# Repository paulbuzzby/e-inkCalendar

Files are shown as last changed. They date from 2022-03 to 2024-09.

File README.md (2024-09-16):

# e-inkCalendar

This repo contains the code needed to drive a 7.5" e-ink display and act as a calendar. This project uses a battery powered (PiSugar2) Raspberry Pi Zero 2 WH (or install your own headers). Calendar events are retrived from Micrsoft Outlook.com.
The layout is based off how the iOS Outlook client shows calendar information. This felt like the best use for the 480x800 space available in the e-ink display.

This project was inspired by [MagInkCal](https://github.com/speedyg0nz/MagInkCal/blob/main/README.md) and some of his code does appear in this project. That project uses a much bigger e-ink display and they are a lot more expensive than the display I have used here.

I created this project as a way to learn python and github while building something usful. The device is magentically attached to my kitchen fridge. Updates as 6am every morning to show me todays planned events along with as many future events that can fit on the page.
Battery percentage is shown in the top right so you know when to recharge and a timestamp of the last sucessful screen update is shown in the bottom left on the screen.

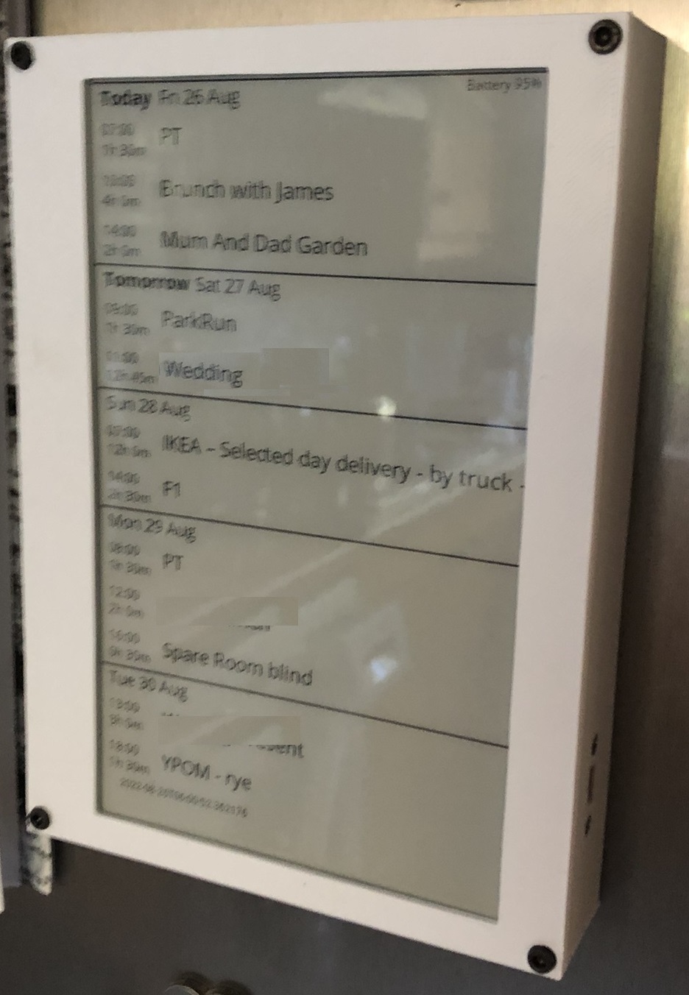
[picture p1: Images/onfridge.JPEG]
On the Fridge


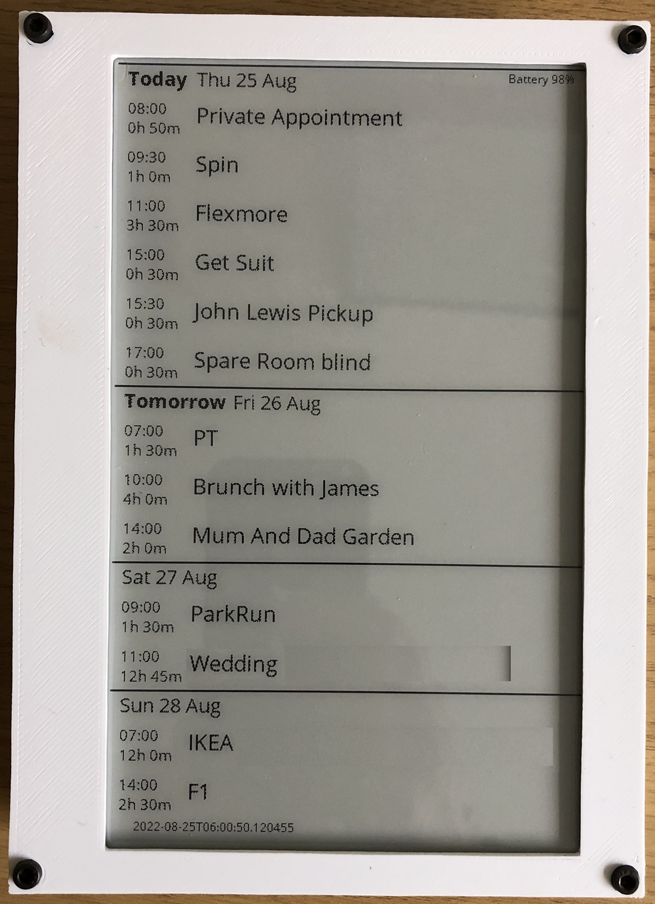
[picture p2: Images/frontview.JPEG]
Front Display


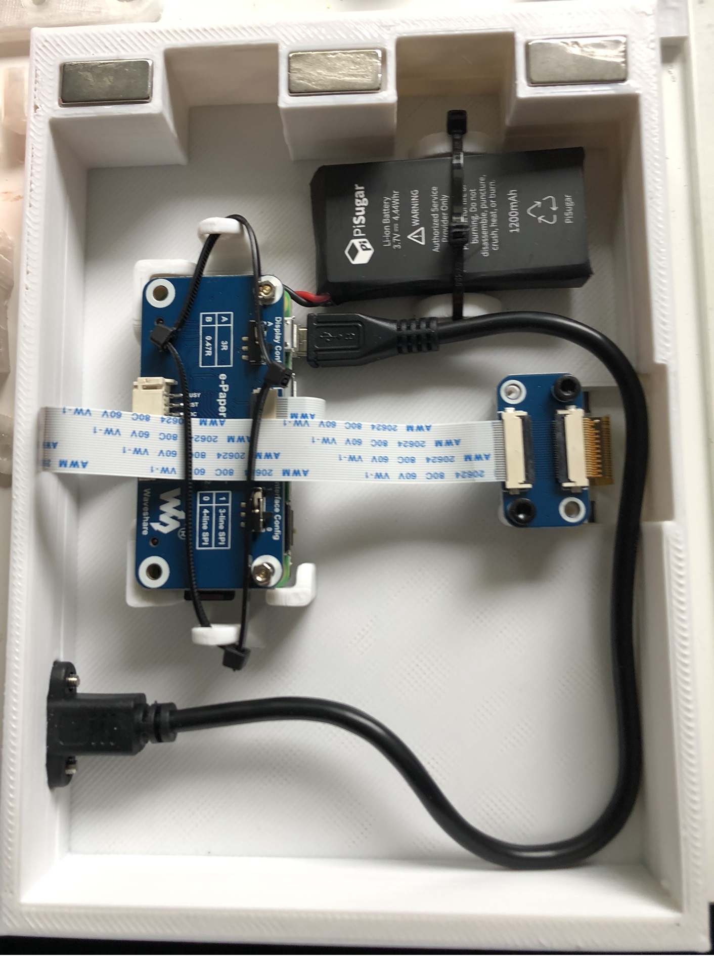
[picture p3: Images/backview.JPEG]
Back Display


## Hardware Required
- [Raspberry Pi Zero 2 WH](https://www.raspberrypi.com/products/raspberry-pi-zero-2-w/) - Header pins are needed to connect to the E-Ink display. A Pi Zero 1 should also work
- [Waveshare 800×480 7.5inch E-Ink display HAT for Raspberry Pi](https://www.waveshare.com/7.5inch-e-paper-hat.htm) - Be careful as there is a version that also does red. While you will be able to make it work the driver code would need changing. Make sure you just buy the black and white display
- [PiSugar2 for Raspberry Pi Zero](https://www.pisugar.com/) ([Tindie](https://www.tindie.com/products/pisugar/pisugar2-battery-for-raspberry-pi-zero/)) - Provides the RTC and battery for this project

- [Magnets 20 x 10 x 2mm](https://www.amazon.co.uk/gp/product/B07VMMK12N) - Glued into the 3D printed case

- [25cm Micro USB USB 2.0 Male Connector to Micro USB 2.0 Female Extension Cable Pitch 17.5mm With screws Panel Mount Hole](https://www.aliexpress.com/item/1005002626850501.html) - Used to make charging easier.

- 6x M3x8 hex bolts to hold the 3D printed case together

- 3D printer - to print the case

## How It Works
Through PiSugar2's web interface, the onboard RTC can be set to wake and trigger the RPi to boot up daily at a time of your preference. Upon boot, a cronjob on the RPi is triggered to run a Python script that fetches calendar events from Microsoft Calendar for the next few days, and formats them into the desired layout before displaying it on the E-Ink display. The RPi then shuts down to conserve battery. The calendar remains displayed on the E-Ink screen, because well, E-Ink...

Features of the calendar: 
- Battery life needs more testing but should last a couple of weeks. The Rpi zero 2 may be more power hungry than the Rpi zero. Retriving the calendar information takes the most amount of time. Maybe this can be optimised. I also have to force a wait command in the CronJob to make sure the system connects to the wifi
- Displays Day and date then lists start time and duration of events
- The calendar always starts from today and fills with as many events that will fit.
- Battery level is displayed in top right corner
- Timestamp of when the last update occured printed on the bottom left of screen

## Bugs / improvement idea's

- Not sure how the system handles events spanning multiple days
- Currently only works against outlook.com calendars
- Would like to add a button to force a refresh

## Share your outlook Calendar

1. Login to [Outlook](www.outlook.com)
2. Top right corner press the Cog (settings)
3. Select the "View all outlook settings" link
* Select Calendar and then Shared calendars
* Under "Publish a calendar" select your calendar and "Can view all details" option
* click the "Publish" link
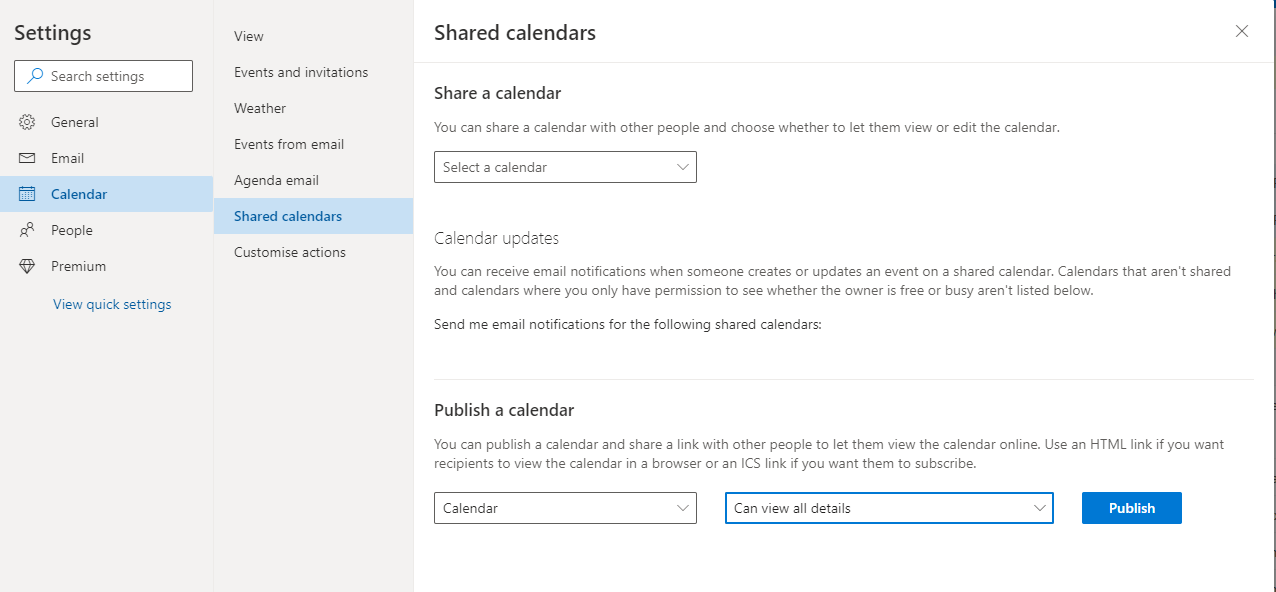
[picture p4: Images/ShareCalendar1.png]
Calendar


* You will then see an ICS link be generated
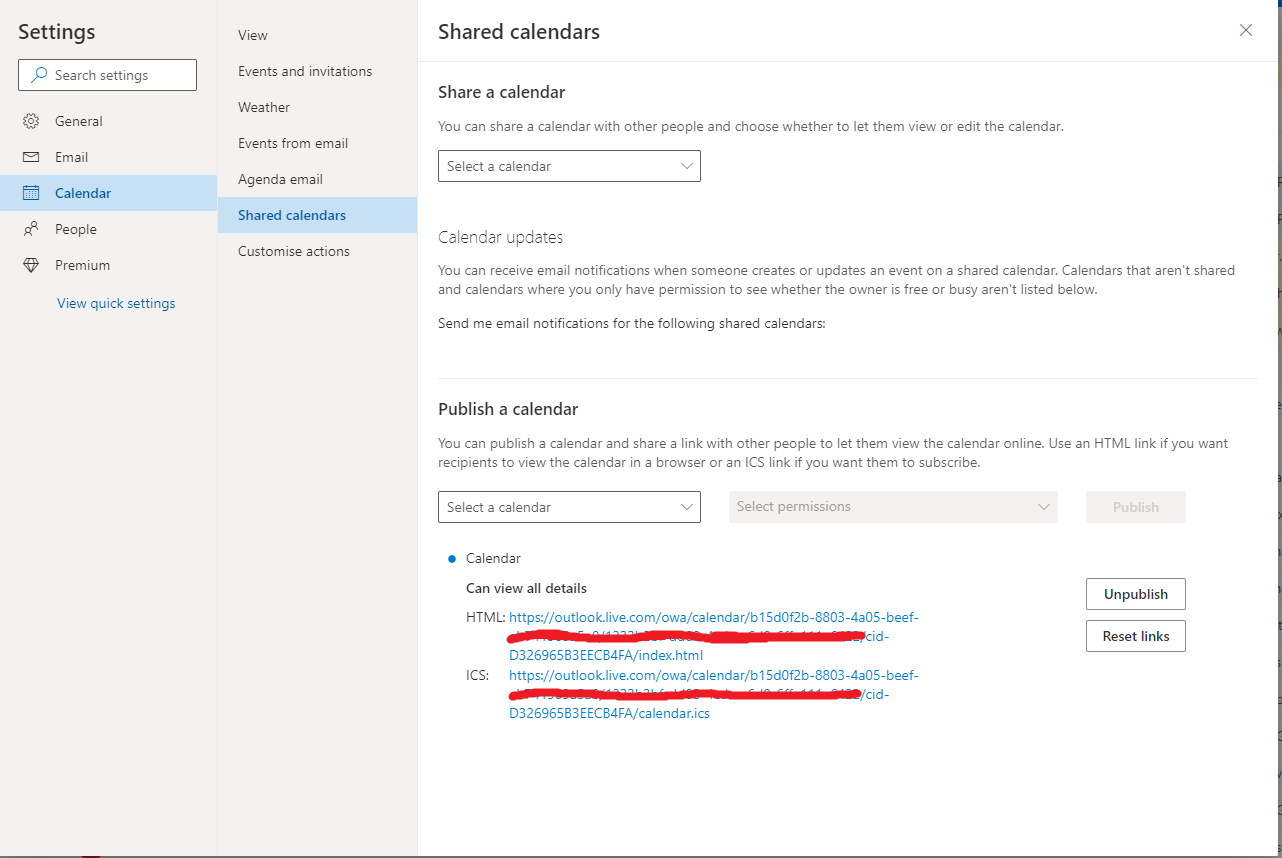
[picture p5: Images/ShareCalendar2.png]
Calendar


**Make a note of the ICS link. You will need it later**

## Setting Up Raspberry Pi Zero
1. Start by flashing [Raspberrypi OS Lite](https://www.raspberrypi.org/software/operating-systems/) to a MicroSD Card. I recommend using the Raspberry Pi Imager. You can then pre-configure Wifi and other information. A great timesaver

2. Install the [PiSugar](https://github.com/PiSugar/PiSugar/wiki/PiSugar2) following their guide
* Configure the Pi to startup at 6am everyday.

3. Install the eInk libries. [Guide here](https://www.waveshare.com/wiki/7.5inch_e-Paper_HAT_Manual#Users_Guides_of_Raspberry_Pi)

* Install BCM2835 libraries
```bash
#Open the Raspberry Pi terminal and run the following command
wget http://www.airspayce.com/mikem/bcm2835/bcm2835-1.71.tar.gz
tar zxvf bcm2835-1.71.tar.gz
cd bcm2835-1.71/
sudo ./configure && sudo make && sudo make check && sudo make install
# For more information, please refer to the official website: http://www.airspayce.com/mikem/bcm2835/
```
* Install WiringPi libraries:

```bash
#Open the Raspberry Pi terminal and run the following command
sudo apt-get install wiringpi
#For Raspberry Pi systems after May 2019 (earlier than before, you may not need to execute), you may need to upgrade:
wget https://project-downloads.drogon.net/wiringpi-latest.deb
sudo dpkg -i wiringpi-latest.deb
gpio -v
# Run gpio -v and version 2.52 will appear. If it does not appear, the installation is wrong
#Bullseye branch system use the following command:
git clone https://github.com/WiringPi/WiringPi
cd WiringPi
./build
gpio -v
# Run gpio -v and version 2.60 will appear. If it does not appear, it means that there is an installation error
```

* Install Python

```bash
sudo apt-get update
sudo apt-get install python3-pip
sudo apt-get install python3-pil
sudo apt-get install python3-numpy
sudo pip3 install RPi.GPIO
sudo pip3 install spidev
```

4. Copy e-inkCalendar folder over to the Pi. I use WinSCP for this task and the folder ends up in /home/pi/e-inkCalendar You can put the code where ever you like but further commands may need to be updated.

5. Install required packages.

Navigate to the e-inkCalendar and run the following

```bash
pip install -r requirements.txt
```

This should install all the required packages

6. Open the config.json file in the e-inkCalendar folder and update the icsURL link with the link you created earlier

7. Run the following command in the RPi Terminal to open crontab.
```bash
sudo crontab -e
```
 Specifically, add the following command to crontab so that the Python script runs each time the RPi is booted up.
```bash
@reboot sleep 20; cd /home/pi/e-inkCalendar && sudo python3 main.py &
```

## Config file
Should look like

```json
{
    "icsURL": "",    
    "dayToCapture": 8,
    "shutdownOnUpdate":true
}
```

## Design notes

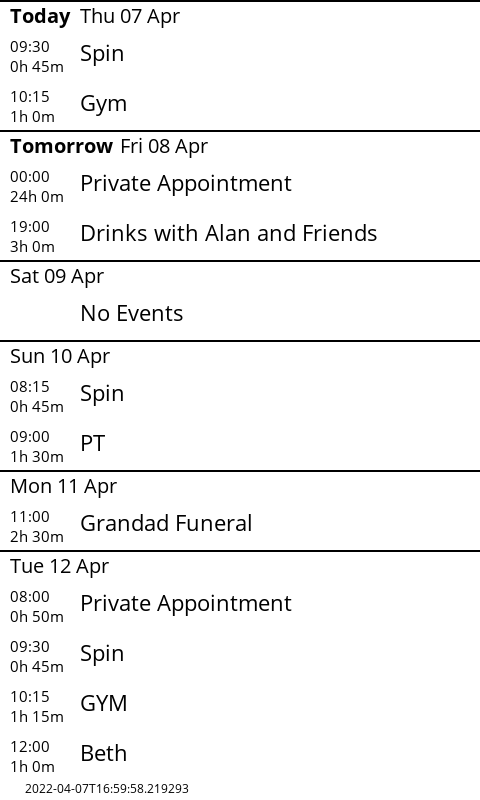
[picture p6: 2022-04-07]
calendar.png

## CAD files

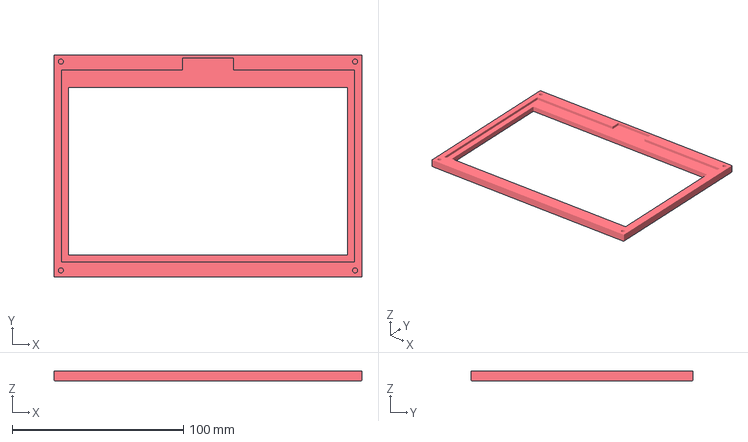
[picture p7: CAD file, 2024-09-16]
Case/TopFrame.3mf
180.0 x 130.0 x 6.00 mm

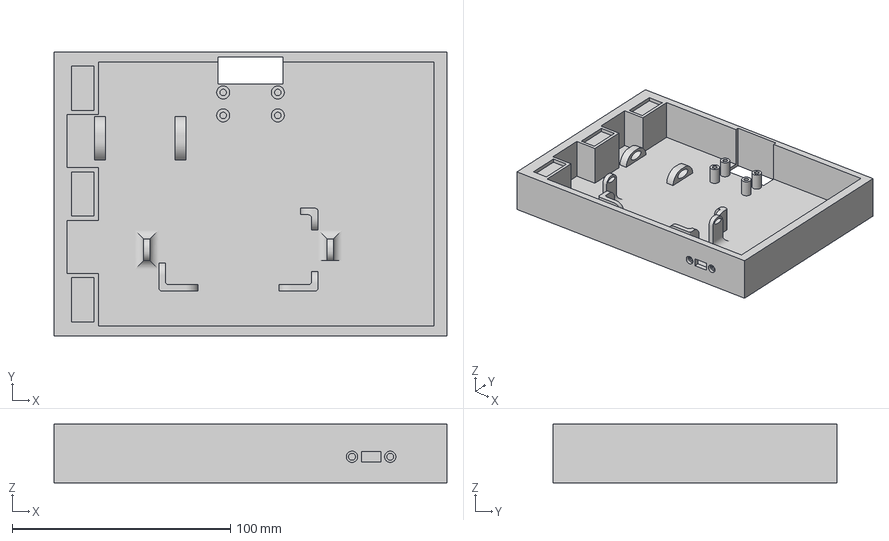
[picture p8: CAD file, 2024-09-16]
Case/BottomFrame.3mf
180.0 x 130.0 x 27.0 mm

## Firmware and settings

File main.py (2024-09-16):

from datetime import datetime
from datetime import timedelta 
import json
import logging
import sys

from ImageCreator import *
from iCalendarHelper import *
import epd7in5_V2
from power import PowerHelper

#Error information if occurs


def main() :
        
    # Create and configure logger
    logging.basicConfig(filename="logfile.log", format='%(asctime)s %(levelname)s - %(message)s', filemode='a')
    logger = logging.getLogger('eInkCalendar')
    logger.addHandler(logging.StreamHandler(sys.stdout))  # print logger to stdout
    logger.setLevel(logging.INFO)
    logger.info("Starting daily calendar update")

    configFile = open('config.json')
    config = json.load(configFile)

    logger.info("JSON config loaded {}".format(config))

    icsLocation = config["icsURL"]
    dayToCapture = config["dayToCapture"]
    shutdownOnUpdate = config["shutdownOnUpdate"]
    
    #dayToCapture
    now = datetime.now()
    now8 = now + timedelta(days=dayToCapture)
    start_date = (now.year, now.month, now.day)
    end_date =   (now8.year, now8.month, now8.day)

    try :
        logger.info("Starting daily calendar update")
        
        powerService = PowerHelper()
        currBatteryLevel = powerService.get_battery()
        logger.info('Battery level at start: {:.3f}'.format(currBatteryLevel))

        
        calendarFile = GetCalendarFile(logger, icsLocation)
        calEvents = ExtractCalendarEvents(calendarFile, start_date, end_date)
        logger.info("Retrived calendar information. Number of items {}".format(len(calEvents)))

        logger.info("Building image")
        eventsImage = BuildEvents(calEvents)
        logger.info("Adding battery info")
        eventsImage = AddBattery(eventsImage,currBatteryLevel)

        epd = epd7in5_V2.EPD()
        
        logger.info("init and Clear")
        epd.init()
        epd.Clear()        

        epd.display(epd.getbuffer(eventsImage))        

        logger.info("Goto Sleep...")
        epd.sleep()

        logger.info("updating clocks")
        powerService.sync_time() #        
        
    except IOError as e:
        logger.info(e)
        
    except KeyboardInterrupt:    
        logger.info("ctrl + c:")
        epd7in5_V2.epdconfig.module_exit()
        exit()

    except Exception as e:
        logger.error(e)

    logger.info("Completed daily calendar update")

    if shutdownOnUpdate :
        #as an extra safty feature check to see if it is the first 5 minutes of the hour as this is when the system will be shedulded to update
        logger.info("Configured to shutdown after update")
        if now.minute in range (0,5):
            logger.info("Shutting down safely.")
            import os
            os.system("sudo shutdown -h now")
    

if __name__ == "__main__":
    main()

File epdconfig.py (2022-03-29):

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

import os
import logging
import sys
import time

logger = logging.getLogger(__name__)


class RaspberryPi:
    # Pin definition
    RST_PIN         = 17
    DC_PIN          = 25
    CS_PIN          = 8
    BUSY_PIN        = 24

    def __init__(self):
        # https://github.com/TCAllen07/raspi-device-mocks

        try:
            import spidev
            import RPi.GPIO

            self.GPIO = RPi.GPIO
            self.SPI = spidev.SpiDev()
        except ImportError:
            from rpidevmocks import MockGPIO, MockSPI
            self.GPIO = MockGPIO()
            self.SPI = MockSPI()

    def digital_write(self, pin, value):
        self.GPIO.output(pin, value)

    def digital_read(self, pin):
        return self.GPIO.input(pin)

    def delay_ms(self, delaytime):
        time.sleep(delaytime / 1000.0)

    def spi_writebyte(self, data):
        self.SPI.writebytes(data)

    def spi_writebyte2(self, data):
        self.SPI.writebytes2(data)

    def module_init(self):
        self.GPIO.setmode(self.GPIO.BCM)
        self.GPIO.setwarnings(False)
        self.GPIO.setup(self.RST_PIN, self.GPIO.OUT)
        self.GPIO.setup(self.DC_PIN, self.GPIO.OUT)
        self.GPIO.setup(self.CS_PIN, self.GPIO.OUT)
        self.GPIO.setup(self.BUSY_PIN, self.GPIO.IN)

        # SPI device, bus = 0, device = 0
        self.SPI.open(0, 0)
        self.SPI.max_speed_hz = 4000000
        self.SPI.mode = 0b00
        return 0

    def module_exit(self):
        logger.debug("spi end")
        self.SPI.close()

        logger.debug("close 5V, Module enters 0 power consumption ...")
        self.GPIO.output(self.RST_PIN, 0)
        self.GPIO.output(self.DC_PIN, 0)

        self.GPIO.cleanup([self.RST_PIN, self.DC_PIN, self.CS_PIN, self.BUSY_PIN])


class JetsonNano:
    # Pin definition
    RST_PIN         = 17
    DC_PIN          = 25
    CS_PIN          = 8
    BUSY_PIN        = 24

    def __init__(self):
        import ctypes
        find_dirs = [
            os.path.dirname(os.path.realpath(__file__)),
            '/usr/local/lib',
            '/usr/lib',
        ]
        self.SPI = None
        for find_dir in find_dirs:
            so_filename = os.path.join(find_dir, 'sysfs_software_spi.so')
            if os.path.exists(so_filename):
                self.SPI = ctypes.cdll.LoadLibrary(so_filename)
                break
        if self.SPI is None:
            raise RuntimeError('Cannot find sysfs_software_spi.so')

        import Jetson.GPIO
        self.GPIO = Jetson.GPIO

    def digital_write(self, pin, value):
        self.GPIO.output(pin, value)

    def digital_read(self, pin):
        return self.GPIO.input(self.BUSY_PIN)

    def delay_ms(self, delaytime):
        time.sleep(delaytime / 1000.0)

    def spi_writebyte(self, data):
        self.SPI.SYSFS_software_spi_transfer(data[0])

    def module_init(self):
        self.GPIO.setmode(self.GPIO.BCM)
        self.GPIO.setwarnings(False)
        self.GPIO.setup(self.RST_PIN, self.GPIO.OUT)
        self.GPIO.setup(self.DC_PIN, self.GPIO.OUT)
        self.GPIO.setup(self.CS_PIN, self.GPIO.OUT)
        self.GPIO.setup(self.BUSY_PIN, self.GPIO.IN)
        self.SPI.SYSFS_software_spi_begin()
        return 0

    def module_exit(self):
        logger.debug("spi end")
        self.SPI.SYSFS_software_spi_end()

        logger.debug("close 5V, Module enters 0 power consumption ...")
        self.GPIO.output(self.RST_PIN, 0)
        self.GPIO.output(self.DC_PIN, 0)

        self.GPIO.cleanup([self.RST_PIN, self.DC_PIN, self.CS_PIN, self.BUSY_PIN])


if os.path.exists('/sys/bus/platform/drivers/gpiomem-bcm2835'):
    implementation = RaspberryPi()
else:
    implementation = JetsonNano()

for func in [x for x in dir(implementation) if not x.startswith('_')]:
    setattr(sys.modules[__name__], func, getattr(implementation, func))


### END OF FILE ###

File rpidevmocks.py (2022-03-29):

#!/usr/bin/env python
# mocks.py: Mock objects for low-level peripheral/hardware-related modules

''' To-Do:
 - add iterable support channels passed to GPIO
 - add GPIO pull-up/pull-down support
 - add event detection support
'''


__author__ = 'Trevor Allen'

# Standard Library
import random
import time
import math

## RPi.GPIO pins (from http://elinux.org/RPi_Low-level_peripherals):
'''
    RPi A+ & B+ GPIO: J8 40-pin header
    --------------------------------
            +3V3 1  2   +5V
    GPIO2   SDA1 3  4   +5V
    GPIO3   SCL1 5  6   GND
    GPIO4   GCLK 7  8   TXD0  GPIO14
             GND 9  10  RXD0  GPIO15
    GPIO17  GEN0 11 12  GEN1  GPIO18
    GPIO27  GEN2 13 14  GND
    GPIO22  GEN3 15 16  GEN4  GPIO23
            +3V3 17 18  GEN5  GPIO24
    GPIO10  MOSI 19 20  GND
    GPIO9   MISO 21 22  GEN6  GPIO25
    GPIO11  SCLK 23 24  CE0_N GPIO8
             GND 25 26  CE1_N GPIO7
    EEPROM ID_SD 27 28  ID_SC EEPROM
    GPIO5        29 30  GND
    GPIO6        31 32        GPIO12
    GPIO13       33 34  GND
    GPIO19       35 36        GPIO16
    GPIO26       37 38        GPIO20
             GND 39 40        GPIO21
    --------------------------------
    '''


class MockSMBus(object):
    ''' Mock of smbus.SMBus() class '''
    mpu_adr = 0x68
    lcd_adr = 0x27
    pwr_mgt_1 = 0x6b
    ## HIGH byte registers for MPU-6050, value+1 for LOW registers
    accel_x = 0x3b
    accel_y = 0x3d
    accel_z = 0x3f
    gyro_x = 0x43
    gyro_y = 0x45
    gyro_z = 0x47
    temp = 0x41

    def __init__(self, bus_no):
        self.bus_no = bus_no

    def __repr__(self):
        return "<Mock: smbus.SMBus>"

    def write_byte(self, addr, cmd):
        if addr not in (self.mpu_adr, self.lcd_adr):
            errmsg = 'Address argument not valid: %s' % hex(addr)
            raise ValueError(errmsg)
        return None

    def write_byte_data(self, addr, cmd, zero=0):
        ''' orig: sensor.Sensor.initialize() '''
        # res = bus.write_byte_data(0x68, 0x6b, 0)  # res = None
        if addr not in (self.mpu_adr, self.lcd_adr):
            errmsg = 'Address argument not valid: %s' % hex(addr)
            raise ValueError(errmsg)
        ## This is specific to MPU
        if cmd not in (self.mpu_adr, self.lcd_adr, self.pwr_mgt_1, self.accel_x, self.accel_y,
                    self.accel_z, self.gyro_x, self.gyro_y, self.gyro_z, self.temp):
            raise ValueError('Command invalid: %s' % hex(cmd))
        return None

    def write_block_data(self, addr, cmd, data):
        # I don't think this is actually used, just available in lcd_device.py
        if addr not in (self.mpu_adr, self.lcd_adr):
            errmsg = 'Address argument not valid: %s' % hex(addr)
            raise ValueError(errmsg)
        return None

    def read_byte_data(self, addr, cmd):
        ''' orig: sensor.Sensor.read_word() '''
        # addr is mpu-addr (0x68); cmd is HIGH register: accel-x (0x3b), accel-y (0x3d),
        # accel-z (0x3f), gyro-x (0x43), gyro-y (0x45), gyro-z (0x47), temp (0x41)
        results = { self.accel_x : 246, self.accel_x+1 : 88,
                    self.accel_y : 4, self.accel_y+1 : 92,
                    self.accel_z : 57, self.accel_z+1 : 104,
                    self.gyro_x : 6, self.gyro_x+1 : 42,
                    self.gyro_y : 0, self.gyro_y+1 : 184,
                    self.gyro_z : 255, self.gyro_z+1 : 216,
                    self.temp : 240, self.temp+1 : 16,
                    self.lcd_adr : 0
                    }
        if addr not in (self.mpu_adr, self.lcd_adr):
            errmsg = 'Address argument not valid: %s' % hex(addr)
            raise ValueError(errmsg)
        ## This is specific to MPU
        ### Checking commands restricts to MPU, disallows LCD display,
        #   unless one were to add all the LCD attributes below to this class
        if cmd not in results.keys():
            raise ValueError('Argument %s not a valid command.' % hex(cmd))
        try:
            return results[cmd]
        except KeyError:
            return None

    def read_byte(self, addr):
        # I don't think this is actually used, just available in lcd_device.py
        if addr not in (self.mpu_adr, self.lcd_adr):
            errmsg = 'Address argument not valid: %s' % hex(addr)
            raise ValueError(errmsg)
        return None

    def read_block_data(self, addr, cmd):
        # I don't think this is actually used, just available in lcd_device.py
        if addr not in (self.mpu_adr, self.lcd_adr):
            errmsg = 'Address argument not valid: %s' % hex(addr)
            raise ValueError(errmsg)
        return None



class Mock_smbusModule(object):
    ''' Mock of smbus module, containing SMBus class '''
    ### Purpose here is to allow instantiation of a fake smbus 'library'
    #   like so: smbus = Mock_smbusModule(); bus = smbus.SMBus(1)
    SMBus = MockSMBus
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

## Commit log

2022-03-29 Battery and MOCK APIs
2022-04-07 Fixed big with missing days
    [CreateCalendarImage.py, ImageCreator.py, iCalendarEventsTest.py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]
2022-04-14 fixed bug where 800+px image could be built
    [ImageCreator.py]
2022-08-24 Updated install instructions
    [BottomFrame.3mf, TopFrame.3mf]
